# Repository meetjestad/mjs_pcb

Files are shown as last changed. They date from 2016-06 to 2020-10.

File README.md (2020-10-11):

Meetjestad PCB repository
=========================

This repository contains various versions of the sensor station PCB used
by [Meetjestad](https://www.meetjestad.net).

The easiest way to see the various version is to have a look at the
releases on Github, which are tagged with the version number. The
release pages also contain rendered (PDF) schematics and board files.

Software
--------
These boards can be programmed using the Arduino environment. The
necessary configuration and support files to allow this, along with
instructions can be found in the [mjs_boards
repository](https://github.com/meetjestad/mjs_boards).

The firmware typically used on these boards is published in the
[mjs_firmware repository](https://github.com/meetjestad/mjs_firmware).

License
-------
The original MJS sensor board is designed by Harmen Zijp, together with
Matthijs Kooijman.

The design for this board is open hardware and licensed
under the the CERN-OHL-W v2 license. Any designs derived from or
containing parts of this design must be similarly licensed. See the
LICENSE file for the full license text.

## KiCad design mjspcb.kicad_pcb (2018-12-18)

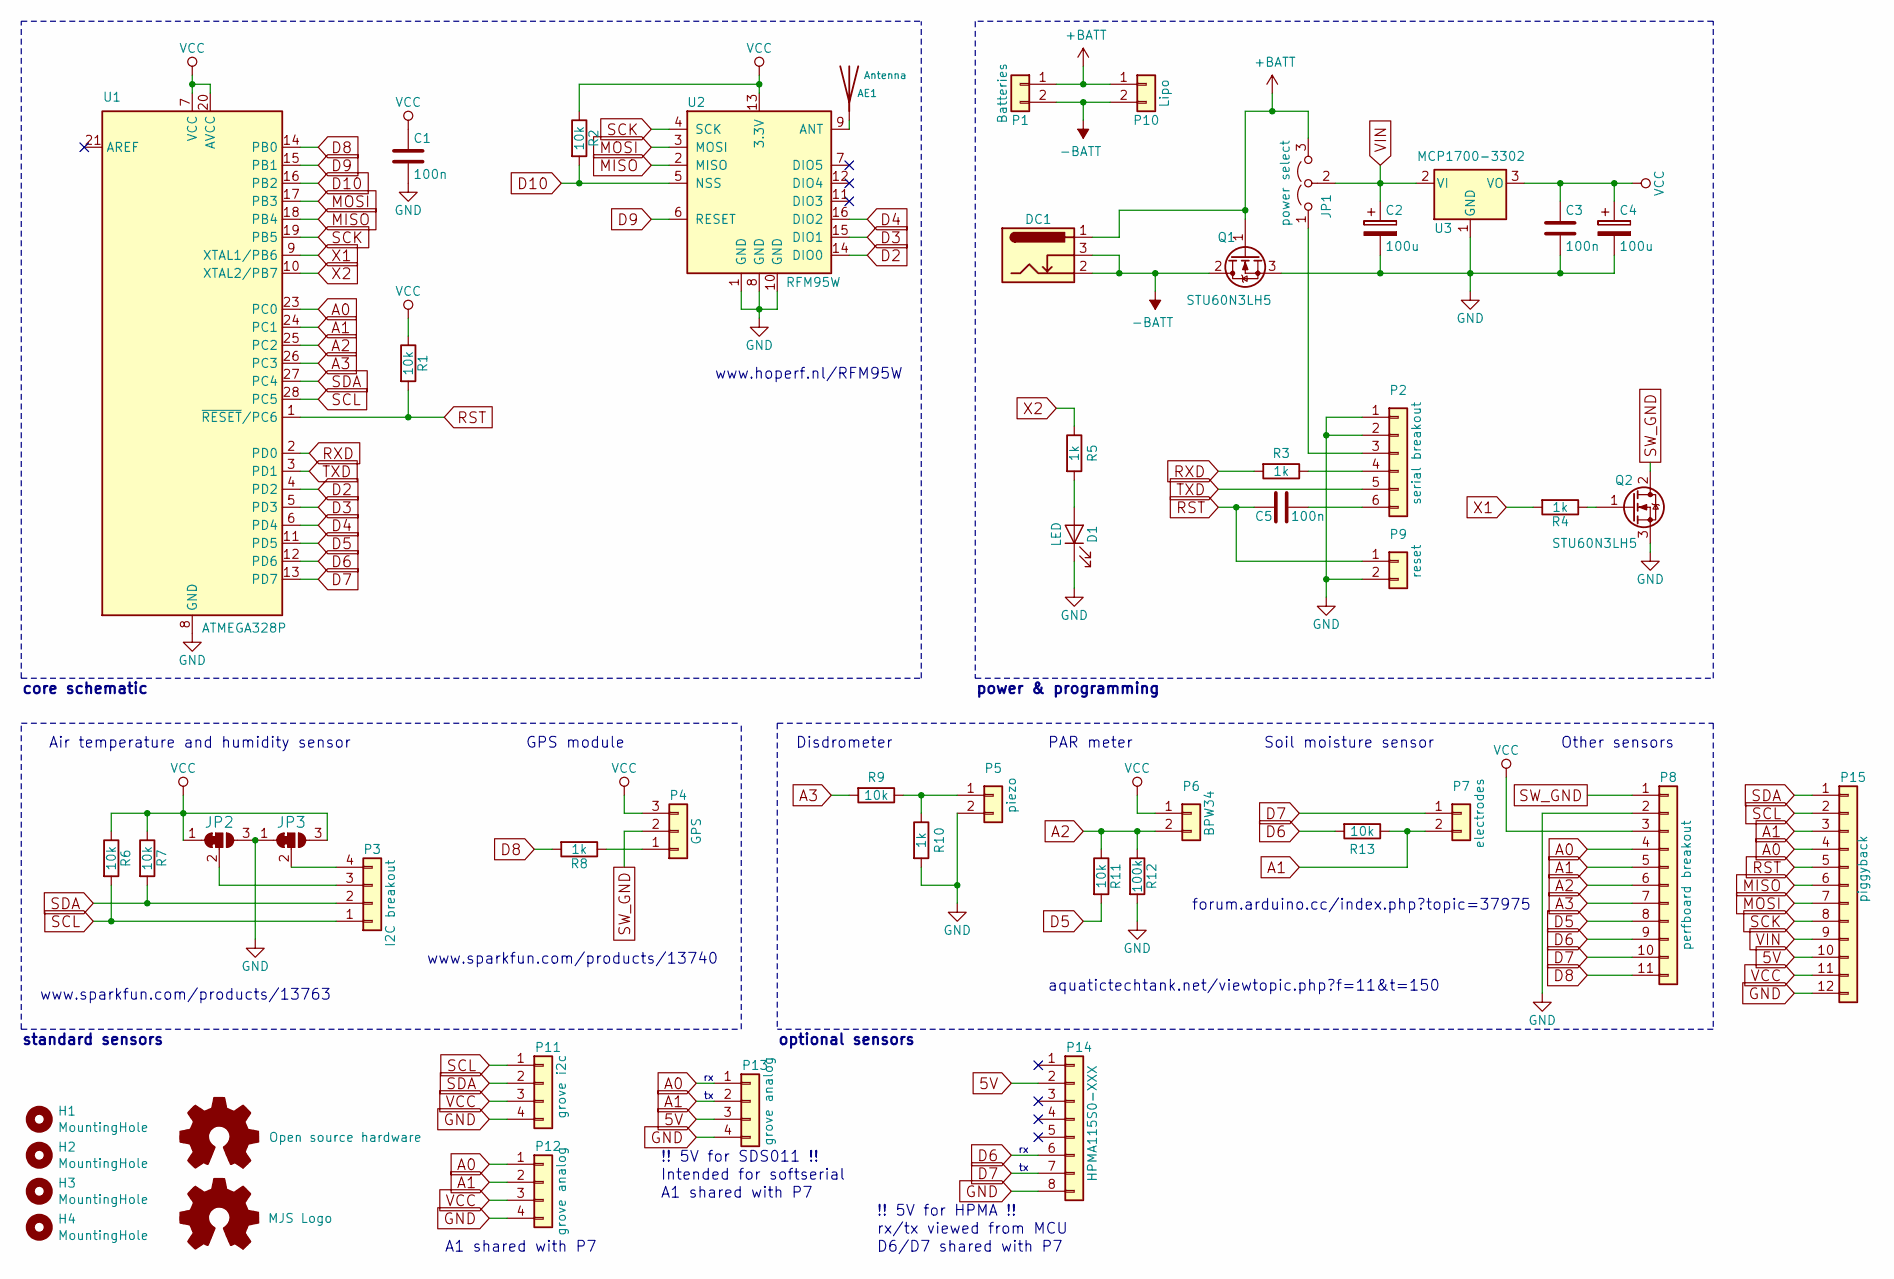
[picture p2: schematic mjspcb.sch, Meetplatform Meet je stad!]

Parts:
AE1: Antenna; PinHeader_1x01_P2.54mm_Vertical
C1, C3, C5: 100n; C_Disc_D3.0mm_W1.6mm_P2.50mm
C2, C4: 100u; CP_Radial_D5.0mm_P2.00mm
D1: LED; LED_D3.0mm
DC1: 2.7 - 6.0 VDC; BarrelJack_Wuerth_6941xx301002
H1, H2, H3, H4: MountingHole; MountingHole_3mm
JP1: power select; PinHeader_1x03_P2.54mm_Vertical
JP2: V1; SolderJumper-3_P1.3mm_Bridged12_RoundedPad1.0x1.5mm_NumberL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
JP3: V2; SolderJumper-3_P1.3mm_Bridged12_RoundedPad1.0x1.5mm_NumberL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
LOGO1: Open source hardware; OSHW-Logo_5.7x6mm_SilkScreen
LOGO2: MJS Logo; mjs
P1: Batteries; BatteryHolder_Keystone_2479_3xAAA
P2: serial breakout; PinHeader_1x06_P2.54mm_Vertical
P3: I2C breakout; Molex_KK-254_44812-0004_1x04_P2.54mm_Vertical
P4: GPS; JST_PH_S3B-PH-K_1x03_P2.00mm_Horizontal
P5: piezo; Molex_KK-254_AE-6410-02A_1x02_P2.54mm_Vertical
P6: BPW34; Molex_KK-254_AE-6410-02A_1x02_P2.54mm_Vertical
P7: electrodes; Molex_KK-254_AE-6410-02A_1x02_P2.54mm_Vertical
P8: perfboard breakout; PinHeader_1x11_P2.54mm_Vertical
P9: reset; PinHeader_1x02_P2.54mm_Vertical
P10: Lipo; JST_PH_S2B-PH-K_1x02_P2.00mm_Horizontal
P11: grove i2c; NS-Tech_Grove_1x04_P2mm_Vertical
P12: grove analog; NS-Tech_Grove_1x04_P2mm_P2.54mm_Vertical
P13: grove analog; NS-Tech_Grove_1x04_P2mm_P2.54mm_Vertical_Alternative
P14: HPMA115S0-XXX; Molex_PicoBlade_53047-0810_1x08_P1.25mm_Vertical
P15: piggyback; PinHeader_1x12_P2.54mm_Vertical
Q1, Q2: STU60N3LH5; TO-251-3_Vertical
R1, R2, R6, R7, R9, R11, R13: 10k; R_Axial_DIN0207_L6.3mm_D2.5mm_P10.16mm_Horizontal
R3, R4, R5, R8, R10: 1k; R_Axial_DIN0207_L6.3mm_D2.5mm_P10.16mm_Horizontal
R12: 100k; R_Axial_DIN0207_L6.3mm_D2.5mm_P10.16mm_Horizontal
U1: ATMEGA328P; DIP-28_W7.62mm_Socket
U2: RFM95W; HOPERF_RFM9XW_SMD
U3: MCP1700-3302; TO-92_Inline

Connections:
5V: P13.3, P14.2, P15.10
+BATT: DC1.1, JP1.3 (B), P1.1, P10.1, Q1.1 (G)
-BATT: DC1.2, DC1.3, P1.2, P10.2, Q1.2 (D)
A0: P8.4, P12.1, P13.1, P15.4, U1.23 (PC0)
A1: P7.2, P8.5, P12.2, P13.2, P15.3, R13.1, U1.24 (PC1)
A2: P6.2, P8.6, R11.1, R12.1, U1.25 (PC2)
A3: P8.7, R9.2, U1.26 (PC3)
D2: U1.4 (PD2), U2.14 (DIO0)
D3: U1.5 (PD3), U2.15 (DIO1)
D4: U1.6 (PD4), U2.16 (DIO2)
D5: P8.8, R11.2, U1.11 (PD5)
D6: P8.9, P14.6, R13.2, U1.12 (PD6)
D7: P7.1, P8.10, P14.7, U1.13 (PD7)
D8: P8.11, R8.2, U1.14 (PB0)
D9: U1.15 (PB1), U2.6 (RESET)
D10: R2.2, U1.16 (PB2), U2.5 (NSS)
GND: C1.2, C2.2, C3.2, C4.2, D1.1 (K), JP2.3 (B), JP3.1 (A), P2.1, P2.2, P5.2, P8.2, P9.2, P11.4, P12.4, P13.4, P14.8, P15.12, Q1.3 (S), Q2.3 (S), R10.2, R12.2, U1.8 (GND), U1.22 (GND), U2.1 (GND), U2.8 (GND), U2.10 (GND), U3.1 (GND)
MISO: P15.6, U1.18 (PB4), U2.2 (MISO)
MOSI: P15.7, U1.17 (PB3), U2.3 (MOSI)
unnamed: AE1.1, U2.9 (ANT)
unnamed: C5.1, P2.6
unnamed: D1.2 (A), R5.2
unnamed: JP1.1 (A), P2.3
unnamed: JP2.2 (C), P3.3
unnamed: JP3.2 (C), P3.4
unnamed: P2.4, R3.1
unnamed: P4.1, R8.1
unnamed: P5.1, R9.1, R10.1
unnamed: Q2.1 (G), R4.1
RST: C5.2, P9.1, P15.5, R1.2, U1.1 (~RESET~/PC6)
RXD: R3.2, U1.2 (PD0)
SCK: P15.8, U1.19 (PB5), U2.4 (SCK)
SCL: P3.1, P11.1, P15.2, R6.2, U1.28 (PC5)
SDA: P3.2, P11.2, P15.1, R7.2, U1.27 (PC4)
SW_GND: P4.2, P8.1, Q2.2 (D)
TXD: P2.5, U1.3 (PD1)
VCC: C1.1, C3.1, C4.1, JP2.1 (A), JP3.3 (B), P4.3, P6.1, P8.3, P11.3, P12.3, P15.11, R1.1, R2.1, R6.1, R7.1, U1.7 (VCC), U1.20 (AVCC), U2.13 (3.3V), U3.3 (VO)
VIN: C2.1, JP1.2 (C), P15.9, U3.2 (VI)
X1: R4.2, U1.9 (XTAL1/PB6)
X2: R5.1, U1.10 (XTAL2/PB7)

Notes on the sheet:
Disdrometer
aquatictechtank.net/viewtopic.php?f=11&t=150
forum.arduino.cc/index.php?topic=37975
www.sparkfun.com/products/13740
www.sparkfun.com/products/13763
core schematic
optional sensors
PAR meter
Soil moisture sensor
power & programming
standard sensors
GPS module
Air temperature and humidity sensor
www.hoperf.nl/RFM95W
Other sensors
!! 5V for SDS011 !!
!! 5V for HPMA !!
A1 shared with P7
rx/tx viewed from MCU
Intended for softserial
D6/D7 shared with P7

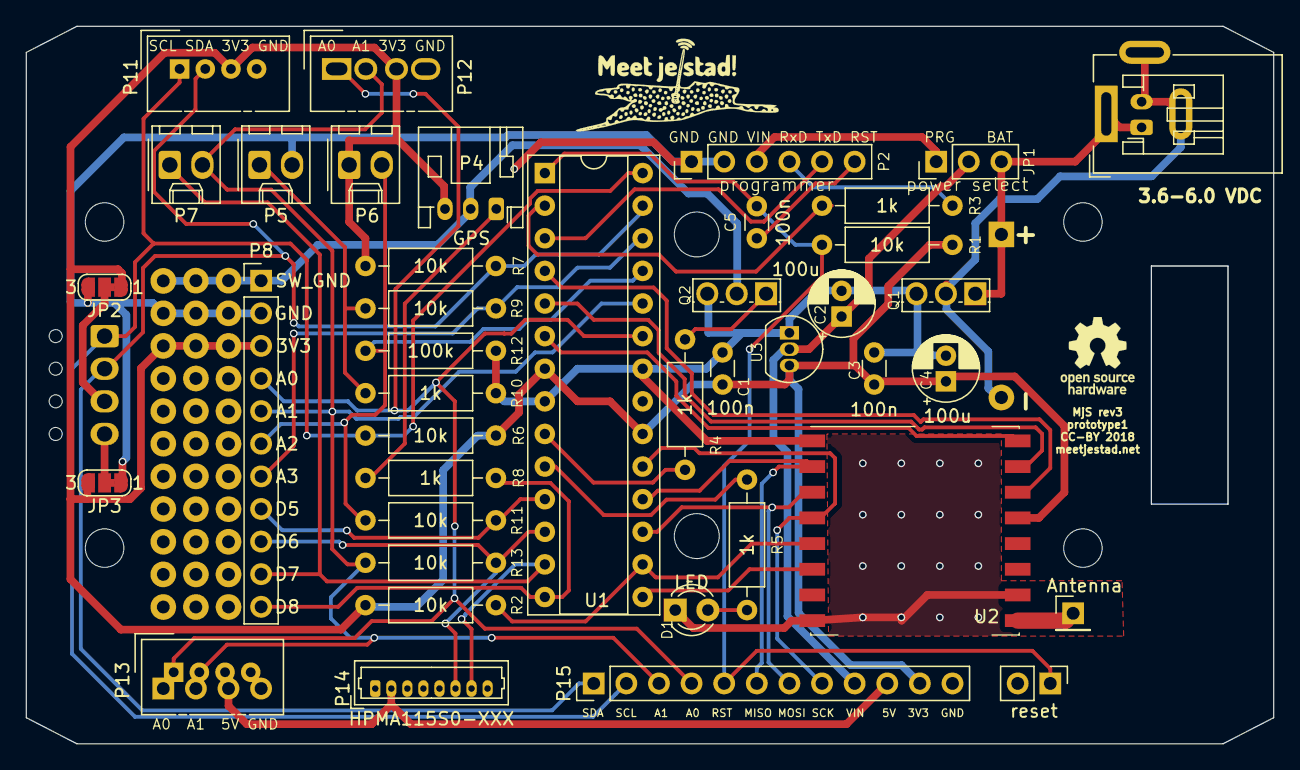
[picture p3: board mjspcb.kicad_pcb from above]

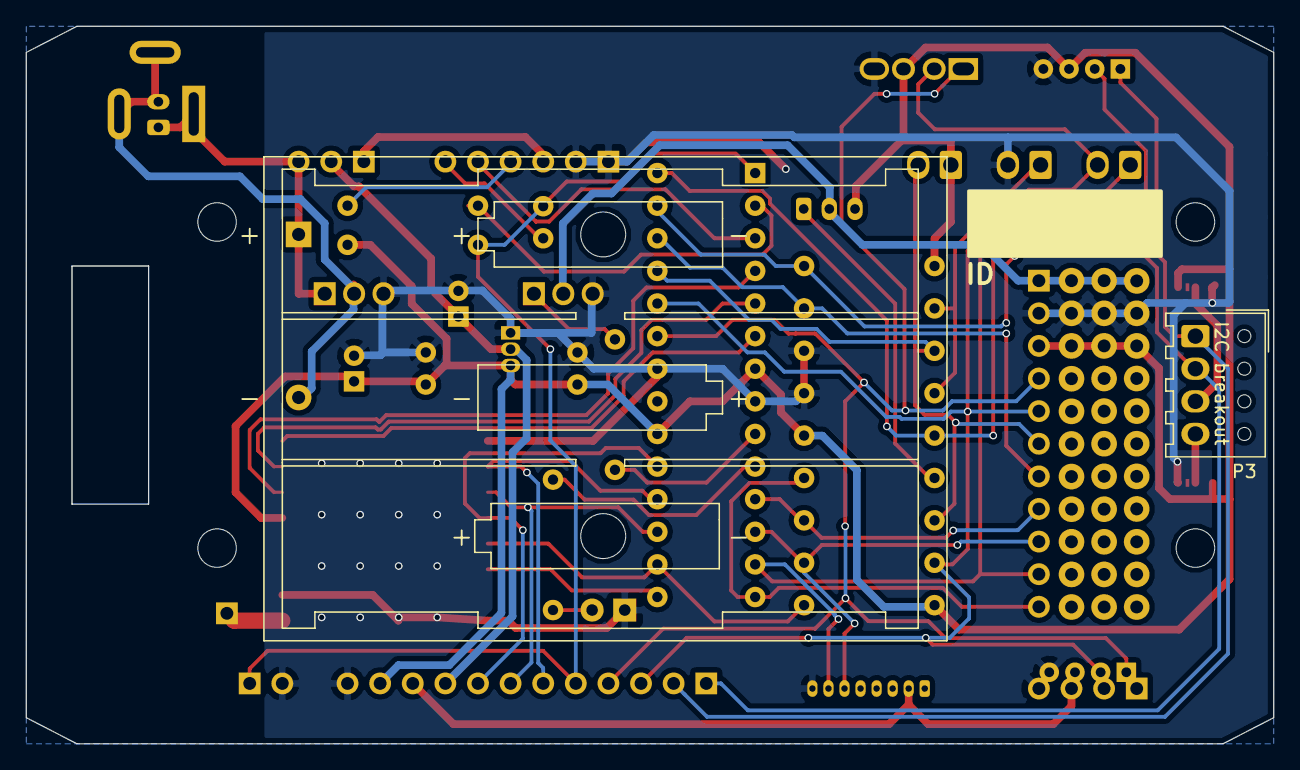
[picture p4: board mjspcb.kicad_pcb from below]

Board: 2 copper layers, 97.2 x 55.9 mm, 50 parts (2 on the bottom side), 40 nets.

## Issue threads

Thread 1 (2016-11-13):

Improvements for next version

matthijskooijman, 2016-11-13:
- [x] Add solder jumpers to I2C breakout
- [x] Easier way to reset board (header with GND and RESET)
- [x] Change value of C2 and C4 to 100uF
- [x] Add top groundplane under SX and antenna
- [x] Disconnect AREF from VCC
- [ ] ~~Add capacitor on AREF?~~
- [ ] ~~Expose VIN (input to regulator) on experiment area? Does have a small risk of over-voltage on components on accidental short-circuit.~~
- [x] Slightly move serial connector to improve silkscreen readability?

Capacitor on AREF is not essential, but 100nF is recommended for ADC stability. It seems there is some room next to C1 (if you make C1 the AREF capacitor and add a new one for VCC between C1 and U3, moving U3 a bit).

Exposing the reset pin on a header seems tricky in the layout. This could be a normal 2.54mm jumper header to reset using a jumper or other stuff (keys). Or just pads, a bit closer together, so you can reset using keys or similar tools without having to solder on pins? Might not be entirely reliable, with pins is probably easier. It seems there is some room in the top right, next to the power jumper to put a reset jumper, routing the RESET line on the top between pin 1 and 2 of the power jumper.

giplt, 2017-04-12:
- [x] Add solder jumpers to I2C breakout
- [x] Change value of C2 and C4 to 100uF
- [x] Disconnect AREF from VCC
- [ ] Add top groundplane under SX and antenna
- [ ] Slightly move serial connector to improve silkscreen readability?
- [ ] Easier way to reset board (header with GND and RESET)
- [ ] Expose VIN (input to regulator) on experiment area? Does have a small risk of over-voltage on components on accidental short-circuit.

Closed 2017-05-12.

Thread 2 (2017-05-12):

Improvements for next version

matthijskooijman, 2017-05-12:
[ ]: Improve footprint for GPS connector, the holes seem slightly too small (+0.1mm is probably enough).

matthijskooijman, 2018-11-23:
Support for dust sensor? https://sensing.honeywell.com/HPMA115S0-XXX-particle-sensors or SDS-11?

matthijskooijman, 2018-11-23:
Maybe use a bigger atmel chip for a bit more flash & ram? Though it seems the only bigger chips also have a bigger pin count (e.g. 644PA and 1284P) and a wider chip.

The 328PB also seems interesting (version of the 328P with extra UARTs, SPI, etc, but it seems there is no DIP version of it....).

matthijskooijman, 2018-11-29:
Maybe we could add V-USB for programming? That certainly requires more flash.

We want to add the option to add a piggypack pcb later, for:
 - Supplying power (from solar or otherwise harvested)
 - Adding a secondary MCU for more complex sensors (e.g. for more flash size and more specific connectors).

matthijskooijman, 2018-12-06:
Seems that V-USB needs at least 12Mhz, so that precludes the internal oscillator on most chips (though it seems some chips have a PLL to allow doubling the oscillator frequency, and can even calibrate it to the USB SOF messages, such as the attiny45 used [in this examplle](https://www.obdev.at/products/vusb/easylogger.html)).

There are bootloaders available that use V-USB. Most of them need custom drivers on the host, but it seems [USBAspLoader](https://www.obdev.at/products/vusb/usbasploader.html) emulated an USBAsp AVR programmer and can thus be used through avrdude without additional complexity. It does seem like there has been no development for years, though (github does have some versions where people added a few patches, but nothing official).

Or perhaps we can add a self-built USB-to-serial on the piggypack using some attiny instead? Then this V-USB-based CDC-ACM stack might be useful: http://www.recursion.jp/prose/avrcdc/

matthijskooijman, 2018-12-06:
For improving the connectors, the Molex KK254 series seems promising and commonly used. These have both board-to-board and wire-to-board options. Figuring out what connectors are available exactly is a bit tricky. [The overview page](https://www.molex.com/molex/products/family?key=kk_254_rpc_connector_system) has a general overview (with a useful PDF under More Info). On RS-online, there is a "line drawing" PDF available for different subseries, which contains a more detailed mapping of the product numbers to the related drawings and options (but this mapping seems to be somewhat irregular, not all numbers are built in the same way, so the line drawing PDF maps these product numbers ("material no" in the PDF) to "Engineer numbers", which reflect the specs completely.

The KK 254 - 4455 series of board-mounted sockets (that accept regular pin headers, or specific KK254 headers with a vertical plastic tab) seems particularly promising. There are angled sockets with hooks that hook around the board edge, There are [vertical sockets](https://nl.rs-online.com/web/p/pcb-sockets/6703196/) which are a bit wider than the default single line sockets, giving them more stability (these have the same hooks as the angled versions, which are not really useful here). Also, there is a ["bottom entry" version](https://nl.rs-online.com/web/p/pcb-sockets/6703143/), which is mounted on the bottom on the PCB, where the pin header of the sensor board would connect through the board, giving a very low-profile connection. RS seems to have these with different contact mechanisms (standard and "Cat ears", which I think refer to the mechanism that the sockets use to clamp the pins inside the socket, cat ears is probably better in some way, but also more than twice as expensive). Molex also offers different contact plating, but it seems RS does not. Farnell has a far more limited selection of these connectors, btw.

I also noticed the KK254 - 44812 series, which has a [low profile socket](https://nl.rs-online.com/web/p/pcb-sockets/4869853/), where the socket is on top of the board, but the pins of the header that is plugged in extend through the board as well.

I'll order a few of these to see how they work.

matthijskooijman, 2018-12-06:
Note that grove connectors are officially "NSTech 1125" connectors, but you can find these in any store. Digikey does sell "grove connectors", which come from Seeed: https://www.digikey.com/product-detail/en/seeed-technology-co-ltd/110990030/1597-1082-ND/5482560 and https://www.digikey.ca/product-detail/en/seeed-technology-co-ltd/110990037/1597-1083-ND/5482561

matthijskooijman, 2018-12-11:
The SDS011 sensor uses a JST XH connector (2.54mm). The sensor has an 8-pin connector (with documented pinout) but often the SDS011 is shipped with an USB-to-serial with a 5-pin JST XH connector and a converter cable (with, to me, unknown pinout). Using the 8-pin connector on the MJS board makes it easy to just order some straight cables, but using a 5-pin connector makes it easier to reuse existing cables...

For the Honeywell sensor, a 8-pin Molex Picoblad connector is used (51021-0800). Due to the small (1.27mm) pitch, it is probably best to use the same 8-pin connector on the MJS board and order some straight cables.

matthijskooijman, 2018-12-11:
For the temp/humidity sensor, apparently Ideetron supplies another breakout that is cheaper, but has a different pinout. Perhaps we should switch to that? We can probably drop the solder jumpers for the original HTU sensor pinout, but perhaps we should have solder jumpers for the to SI sensor pinouts? It would be useful if the HTU sensor connector followed the Grove I2c connector pinout, so if either module does this, we could stick to that one?

matthijskooijman, 2018-12-14:
For attaching a piggyback (power) PCB, the FTDI connector and the power select jumper are good points to connect on. The latter gives access to the battery +, and the regulator input / VIN, so you could even connect a battery charger and/or step up converter there (to put 5V on VIN).

For efficiency, it might be interesting to have 2 different power inputs on the board: 5V (for a dust sensor) and VIN (which can be the raw battery voltage and passes through the linear regulator to produce 3V3 for the MCU and the GPS). These could both be 5V, but that would be less efficient (having to pass through a step-up converter). On older boards, there is no dust sensor, so no 5V needed. IOW, the voltage from (rechargable) batteries or lipo can be attached to VIN directly (on old and new boards). On new boards, an additional 5V circuit can be attached through a new header pin, and supplied either from the piggy-pack's step-up converter, or from the DC barrel jack. This separation probably requires another jumper to select where the 5V comes from (e.g. attach the jumper to connect 5V and VIN together for the barrel jack usecase, or remove the jumper for the 5V and VIN/battery separated usecase with a piggyback). Or make 5V and VIN the same circuit, but then you lose efficiency in the piggyback usecase (and you can no longer disable the step-up converter when you're not powering the dust sensor).
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
matthijskooijman, 2019-01-02:
> One last addition could be considering an optional RJ45 connector to the board. This will allow easy extention of I2C sensors and the particle sensor outside of the node housing. See this as an option.

For now, we're aming for grove connectors as a standard expansion connector for (among others) I2c, since that is a somewhat standardized connector. A downside is that it seems hard or impossible to get separate connectors and you have to buy premade cables instead...

pe1mew, 2019-01-04:
I have evaluated the first prototype board and have these review comments:
## ports linked to connectors:
Currently port A0 and A1 are linked to connector P12, P13 and P15. This will reduce the flexibility for connecting sensors. Therefore I propose to link A2 and A3 to connector P13 and expand P15 with A2 and A3.
## Antenna:
When I use a small helical antenna (which are my preference because of performance) the antenna cannot be properly soldered. I therefore propose to leave out an opening in the PCB for this antenna.
I do propose to add a footprint for a uFL connector. The will allow the use of externa antennas and even better performing antennas than the helical.

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
## Piggyback board obstructed:
The 100 uF capacitors are relatively big. because of this the piggyback board can be lifted by the capacitors. I propose to use smaller capacitor or axial versions instead of radial, Another option is to move the capacitors out of range of the piggy board size.

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
I now have to wait for 10k trough hole resistors to complete the PCB and program is. :-)

matthijskooijman, 2019-01-28:
> Currently port A0 and A1 are linked to connector P12, P13 and P15. This will reduce the flexibility for connecting sensors. Therefore I propose to link A2 and A3 to connector P13 and expand P15 with A2 and A3.

I picked A0 and A1, because they are not used yet in practice at the moment (A0 is completely free, A1 is only used for the soil moisture which we're not actively using yet). Using other pins gives more flexibility in the expansion, at the expense of not being able to use the existing sensor connections at the same time. I'm not so sure what the best approach is here, but I guess a little more variance would be good.

As for the antenna: with a helical antenna, its view might be obstructed by the GPS module, so it might need to be moved up a bit (taking care to make the trace 50Ω). Alternatively, we could have a look at using a PCB trace antenna, which would make the board even simpler in assembly. Adding a u.FL fooptrint is a good idea in any case, for when you need a bit extra range).

As for the capacitors, on our boards I think we use one smaller and on bigger cap (at least in value, not sure about physical size). I'll check a more recent board to see how it is there. IIRC we cannot use the smaller (value) caps in both places, since then the GPS power-on current resets the board...

Also, we could consider switching to a cheaper/better RF module, Thomas Telkamp suggested there are better alternatives. There is also a new transceiver chip that would be more efficient (SX1762), but also is not supported by LMIC at the moment (but there might be a new LMIC-based stack in the near future that does support it).

As for solar, I also heard that Thomas was experimeting with a MPPT chip and a LiPo and found that he could power the board with a very small solar panel too. I'm not sure what the power usage was though, probably without a dust sensor.

matthijskooijman, 2019-05-21:
It turns out the Sensirion SPS30 sensor (that we'll also considering) can do both UART and I²C communication (switched using a pin on power-up). I²C is probably a lot more efficient in terms of code size (mostly due to simpler parsing. Code saved due to reuse of the Wire library is probably comparable with reuse of the SoftwareSerial library). For this to work, we should probably have an I²C port connected to 5V/Vin as well.

We could also consider switching from AAA batteries to AA batteries. Now the pcb is a bit bigger, we have room for that. This would lead to a signficant increase in capacity and battery life.

Alternatively, we could consider switching to 4 or 5 batteries so we can perhaps power the air quality sensors directly from the batteries, without needing a step-up converter (this probably still needs a regulator and needs 5 batteries to allow rechargable batteries, since 4x1.2V is only 4.8V). The downside is that you're wasting more power in the regulator during sleep time, but combined with a solar charger that might not really be relevant.

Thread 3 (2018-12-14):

Design piggyback for v3 PCB

matthijskooijman, 2018-12-14:
This piggyback could be used for:
 - Attaching a solar panel (or other energy collection device) to charge a Lipo or regular rechargeable batteries
 - Provide a step-up to 5V from a battery/LiPo voltage
 - Provide access to additional or more complex sensors

matthijskooijman, 2018-12-15:
For compatibility with the existing v1/v2 PCBs, the piggyback should connect to the FTDI serial connector and the power select header. For v3 boards an additional header can provide more connections (and more stability by putting the header opposite the existing header). For v1/v2 boards, extra connections and stability could perhaps be obtained through the protoboard.

The piggy-back should certainly have access to some datapins. I2c and ISP are obvious, since they can be easily shared. This allows putting an MCU on the piggyback for maintainance tasks, such as reading additional sensors, enabling/disabling a step-up converter, controlling or querying a solar/battery charger, etc. I2c is probably the easiest for this, but it might be good to attach SPI as well as some GPIO pins.

See also https://github.com/meetjestad/mjs_pcb/issues/2#issuecomment-447341849

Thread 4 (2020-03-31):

V3 PCB Considerations: MCU selection

matthijskooijman, 2020-03-31:
For the next generation PCB, we're looking at switching away from the Atmega328p, since it is becoming too small for future additions (see also #2). This issue summarizes some of our previous considerations and offers space for further discussion.

### Package
Ideally, we would use a DIP package, since that is really easy to solder even for novices. However, within the Atmega family, it seems that all chips bigger (in terms of RAM and flash) are also wide dip packages (e.g. the Atmega1284) and a *lot* bigger. Also, these are quite expensive an offer no extra CPU speed compared to the 328p, so some ARM-based chip is probably better.

However, there seem to no viable ARM-based processors in DIP-package, hence the consideration to use a breakout for the MCU, or maybe prepopulate it.

Looking at SMD-packages, QFP is the most common and still hand-solderable, so probably the most viable. We initially limited to QFP-32 packages, since 32-pins seemed to be just enough for our basic design plus some expansion ports and QFP-32 with its 0.80mm pitch is still fairly easy to solder for someone with some experience (QFP-48 and QFP-64 with 0.50mm pitch is already a bit harder). However, if we are going to automated this part of the assembly, QFP-48 and QFP-64 are probably also feasible (QFN is probably a bridge too far).

### SAMD21
Our search mainly looked at the SAMD21 family, since that is used in a lot of Arduino boards and supported by Arduino itself. In addition to the core running on there, the upload method (using a USB bootloader) is probably also well-supported. In our initial testing, we used a SAMD21E (32-pin) with the bootloader from the Adafruit Trinket M0 which uses the same chip (unlike the more commonly used SAMD21G used by Arduino zero and other boards).

### RISC-V
We also considered the RISC-V platform / SiFive processors, but those do not seem to be very mature yet and Arduino support is probably imperfect.

### STM32
STM32 was originally also looked at briefly (mostly looking for any pre-made breakout boards) and later I looked at them in a bit more detail. Since then, I've had a bit more experience with STM32 chips and I think this is a good option. Arduino support is not provided by Arduino itself, but ST has taken maintainance of the [Arduino_Core_STM32](https://github.com/stm32duino/Arduino_Core_STM32) core (there are a few others too) and IMHO is doing a good job at it.

A big advantage of (most) STM32 chips is that (most of) their pins are 5V-tolerant, which is of course helpful to facilitate experimenting with new sensors (even though all specific sensors we are considering now have 3.3V logic).

A challenge is the sketch uploading. The STM32 chips have a builtin ROM bootloader which is convenient (cannot be erased) and often (depends on the chip) can do uploads through USB (using DFU). However, these bootloaders typically listen on one more UARTs, SPI ports, I²C ports, CAN bus, etc. To prevent accidentally putting the bootloader in the wrong mode, these other ports must all have a particular and stable startup state (e.g. SS pins, UART RX, I2C all high).

An alternative is using a custom bootloader occupying the first flash page, of which there are a few available (but I have not looked closely at which, the ones I saw were not that great). There is an Adafruit STM32 board (and reportedly Arduino will release one soon too), so maybe there is some bootloader and other tricks we could copy from there. The Arduino_Core_STM32 also does not have perfect support for USB uploads yet, but I've made some improvements there already and I think those should be usable soon.

If we use a custom bootloader, it would be best if it can be protected somehow, to prevent accidentally overwriting it and preventing further uploads. Protection is typically done at a flash page or section boundary, so this might end up "wasting" some flash space if the bootloader is a lot smaller than that.

### Flash & Memory

Currently, we have a 328p with 32K flash and 2K RAM. For Flash, doubling the amount of space would give a lot of room to play, but might still be a bit limited (especially since compiled programs are typically a bit bigger on ARM I think). Four times as much (128K flash) is probably more than enough, but more does not hurt.

As for RAM, I think most chips of these sizes are 32K+, which should be more than enough.

### Power usage
Currently, the 328p can sleep at < 1μA, which is probably below the self-discharge and below the average current of MCU and sensors while running. Run current is 40mA or so.

For a new chip, a similar sleep current would be nice, though up to a few μA is probably also acceptable.

This sleep mode should retain RAM. Some chips (e.g. STM32G4 and ESP) can only obtain such low-power sleep when disabling RAM. Often, there are a few RTC registers that can be used to save state, but that greatly complicated firmware programming, especially for novice programmers, so that is IMO not acceptable.

### EEPROM
The current 328p has builtin EEPROM that is used to provision it with an id and encryption keys. SAMD21 and most STM32 processors do not seem to have EEPROM built-in, though flash can often be used as an alternative (sometimes there is even a dedicated section of flash that can be used like EEPROM, SAMD21 and some STM32 processors have this).

If a custom bootloader is flashed, we can easily append some id and keys at the end of that flash page as well, since they will be write-once.

Currently, we are not using the EEPROM to remember settings or other things during runtime, but this is something we might add later (for settings to simplify the firmware code, but also for LoRaWAN 1.1 support which requires remembering some information across reboots).

Here is some earlier notes about processor selection from our etherpad:
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
matthijskooijman, 2020-07-02:
We're aiming for STM32 now. KITT has compared a few options, extending to 64-pins rather than 32 or 48, since the plan is to do pick & placing and that gives some more pins for extendability and toggling different power domains.

The current plan is to try STM32L072RZ. I haven't looked at it in detail yet, will try to do so ASAP.

matthijskooijman, 2020-07-17:
The STM32L072 series looks like a very good candidate. In particular:
 - It has 3 or 6kbyte of EEPROM, which is not a given for these STM32 and other ARM chips.
 - It has good low power modes, retaining RAM and running an RTC for wakeup at < 1 μA.
 - It is 5V tolerant on most of its pins.
 - It has crystalless native USB (i.e. using the internal oscillator calibrated against the SOF USB message).
 - It has plenty of peripherals.

It also has plenty of clocking options, running the CPU on the HSI (high-speed internal oscillator) and using the LSE (low-speed external crystal, i.e. 32kiHz) for precision timekeeping (for time of day / sleep intervals and wakeups / LoRa timestamping) would make sense. Not sure how this should be wired exactly (seems that the RTC and LPTIM low-power timer can both run against the LSE, but neither has (sub-second) input-capture to timestamp the LoRa TX-complete interrupt, but that can probably be done using a regular interrupt as well).

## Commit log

2017-11-07 Revision 2 of Meet je stad PCB
    *added reset header
    *changed pinout of I2C breakout to accomodate Sparkfun Si7021
    *various minor other modifications
    [mjspcb-B.Cu.gbr, mjspcb-B.Mask.gbr, mjspcb-B.SilkS.gbr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]
2017-11-07 Updated pdf files for PCB revision 2
2018-12-18 Remove build products
    This removes the gerbers, rendered schematics and bom (in various
    format). These will be outdated during development and only really
    relevant for released version, so they are probably better put in a
    release on github rather than in git.
    [mjspcb-B.Cu.gbr, mjspcb-B.Mask.gbr, mjspcb-B.SilkS.gbr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]
2018-12-18 Convert schematic to KiCad 5
    In KiCad 5, symbols reference the library they are in explicitly. Also,
    a lot of symbols were changed for more consistency. This commit changes
    all symbols to their new version in the official libraries, removing the
    need for our own symbol library (which is removed by this commit).
    For the STU MOSFET component, not specific symbol is available, so a
    generic MOSFET symbol is used instead.
    This also updates the footprint fields to point to versions from the
    KiCad 5 libraries, but does not update the actual layout to use them
    yet.
    For the GPS connector symbol, the pinout was reversed (matching the,
    technically incorrect, footprint used). This fixes the pin order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
    [mjspcb.sch]
2018-12-18 Remove unused footprint libraries
    The libraries referred to are not present in git and are unused, so
    remove them to prevent warnings when loading footprints.
2018-12-18 Fix schematic for reset connector
    In the schematic, the reset pin header was connected to the reset pin in
    the serial header, on the far side of the reset capacitor. However, in
    the board layout, it was connected on the near side of the capacitor,
    directly to the MCU pin. This reflects that.
    [mjspcb.sch]
2018-12-18 Add DC plug and Lipo connector to schematic
    These were in the board layout, but not in the schematic. This adds them
    to the schematic, and sets the appropriate references in the layouted
    footprints.
    Note that the DC plug symbol has a different pin numbering than the
    footprint currently in use, but the symbol does match the footprint set
    in the schematic, so this should work out when the netlist is re-read in
    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
    [mjspcb.kicad_pcb, mjspcb.sch]
2018-12-18 Add mounting holes and logos to the schematic
    This adds them and sets footprints, but does not update the board (not
    even to update the REF properties, since I had too many other changes
    already).
    [mjspcb.sch]
2018-12-18 Convert board layout to KiCad 5
    This replaces all footprints with new versions from KiCad 5. Some
    positions and labeling as changed, so this updates everything to match
    the original layout for the most part. Some footprints (barrel jack,
    regulator, battery holder, solder jumpers, perfboard "connector") are
    slightly different. In particualr the battery holde slightly changes the
    mounting hole position and size, so this might need to be changed back
    later.
    The only footprints that are still used from the project library are the
    logo, all others are removed. All components are also in the schematic,
    except for the perfboard individiual pins (which also do not have any
    external footprint they r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
    [mjspcb.kicad_pcb, mjspcb.sch]
2018-12-18 Fix DRC errors in solder jumper footprint
    This uses a modified solder jumper footprint that has a graphic polygon
    rather than overlapping pads to connect the default pins, which prevents
    DRC errors. See: https://github.com/KiCad/kicad-footprints/issues/1165
    [mjspcb.kicad_pcb, mjspcb.sch]
2018-12-18 Increase board size
    This increases the width to 56mm, so it no longer needs extra plates to
    fit into the housing. The length is also slightly increased (to make
    room to mount the GPS antenna later), but kept within 100mm (which makes
    prototype PCBs a lot cheaper with some suppliers).
    [mjspcb.kicad_pcb]
2018-12-18 Run a track & via cleanup
    [mjspcb.kicad_pcb]
2018-12-18 Add slot for GPS
    This also moves the barrel jack and LiPo connectors to make room for the
    slot, and removes some of the ground plane to prevent interfering with
    the GPS and LoRa antenna.
    [mjspcb.kicad_pcb]
2018-12-18 Fix input voltage range on silkscreen
    This changes the minimum to 3.6V, which should be safe. The MCP1700
    datasheet has a dropout voltage of 178mV typical, 350mV max (at 250mA).
    Given we need a lower current, calculating with a 300mV dropout seems
    ok.
    [mjspcb.kicad_pcb]
2018-12-18 Flip I²C socket
    This swaps the pin numbering, to match the Grove pinout. The PCB layout
    is also updated to flip the footprint, and move a few traces to make
    room for the square pad on the other side.
    [mjspcb.kicad_pcb, mjspcb.sch]
2018-12-18 Replace I²C connector with a more sturdy one
    This one has extra holes to plug in the sensor, so it can be mounted
    lower and more stable. This also makes the board slightly longer at the
    bottom to accomdate the new connector, and shorter at the top.
    [mjspcb.kicad_pcb, mjspcb.sch]
2018-12-18 Replace 2-pin sensor connectors with KK254
    These are latching, polarity protected connectors. This mostly changes
    to silkscreen, though the pads are also slighly differently sized.
    [mjspcb.kicad_pcb, mjspcb.sch]
2018-12-18 Move reset header to fix connections
    This was accidentally disconnected when introducing a keepout zone for
    the antennas recently.
    [mjspcb.kicad_pcb]
2018-12-18 Improve I²C connector
    This removes the plating from the second row of holes, updates the
    footprint metadata and reroutes a trace around it to prevent a DRC
    violation.
    [mjspcb.kicad_pcb]
2018-12-18 Re-add battery compartment
    This was accidentally removed two commits ago.
    [mjspcb.kicad_pcb]
2018-12-18 Add extra connectors to the board
    This adds two connectors for dust sensors (SDS011 and HPMA115S0-XXX) and
    two more generic grove connectors (digital and I²C). It also adds a long
    pin header with assorted connections (I²C, SPI, various power) for use
    with a piggy-back additional PCB which is expected to handle more
    complex power needs.
    For the grove connectors, some custom experimental footprints are added
    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
    [mjspcb.kicad_pcb, mjspcb.sch]
2018-12-18 Merge text under OSHW logo in one element
    Each of three lines were separate text objects, but you can also just
    use newlines in a single text object.
    [mjspcb.kicad_pcb]
2018-12-18 Bump version and copyright year
    [mjspcb.kicad_pcb]

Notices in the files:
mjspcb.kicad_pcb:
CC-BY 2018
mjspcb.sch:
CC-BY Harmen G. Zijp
